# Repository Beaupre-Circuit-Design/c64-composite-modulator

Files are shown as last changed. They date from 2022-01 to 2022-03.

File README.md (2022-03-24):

# c64-rf-modulator-replacement
C64 Composite/S-Video RF Modulator Replacement

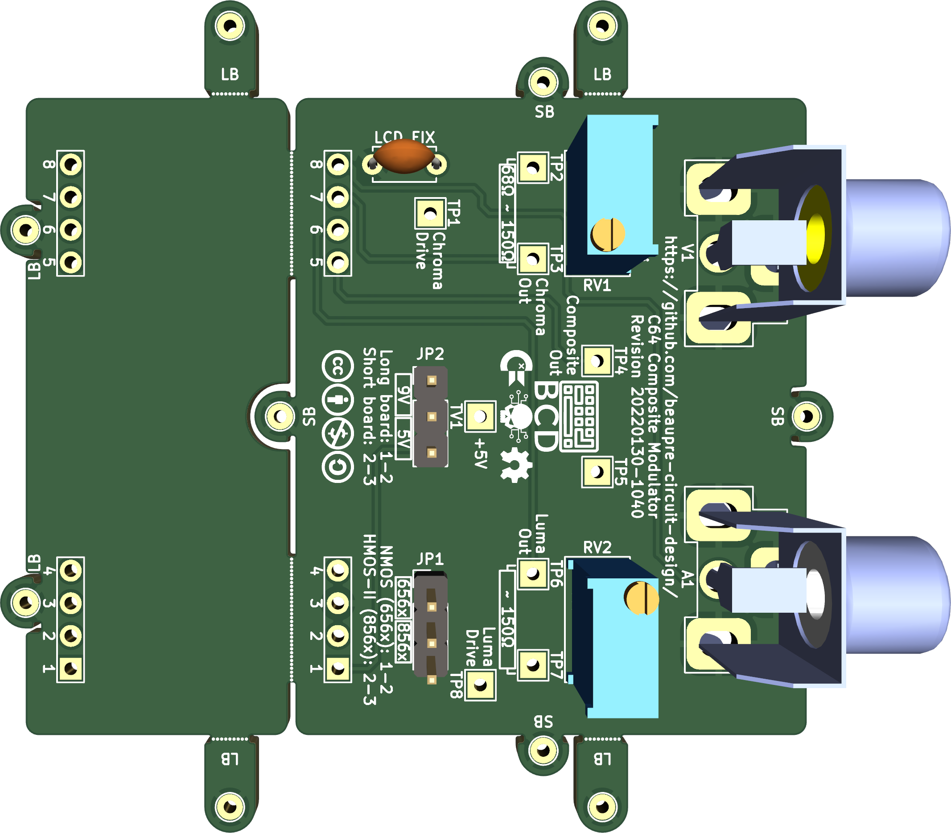
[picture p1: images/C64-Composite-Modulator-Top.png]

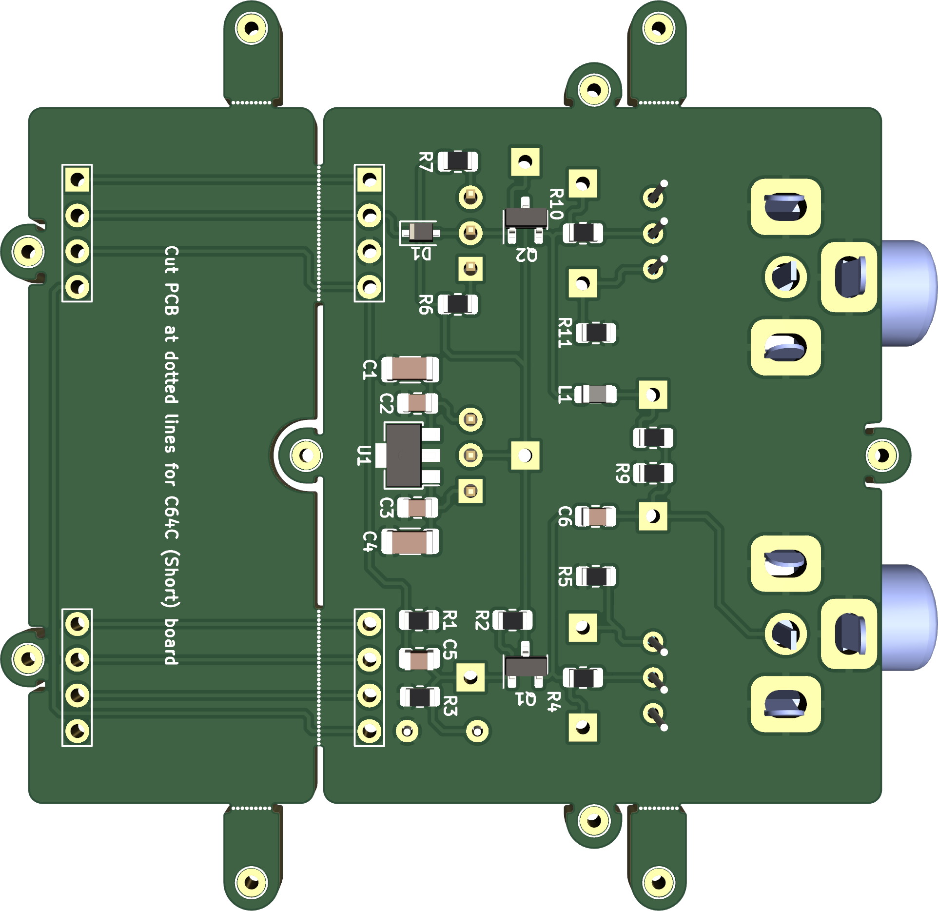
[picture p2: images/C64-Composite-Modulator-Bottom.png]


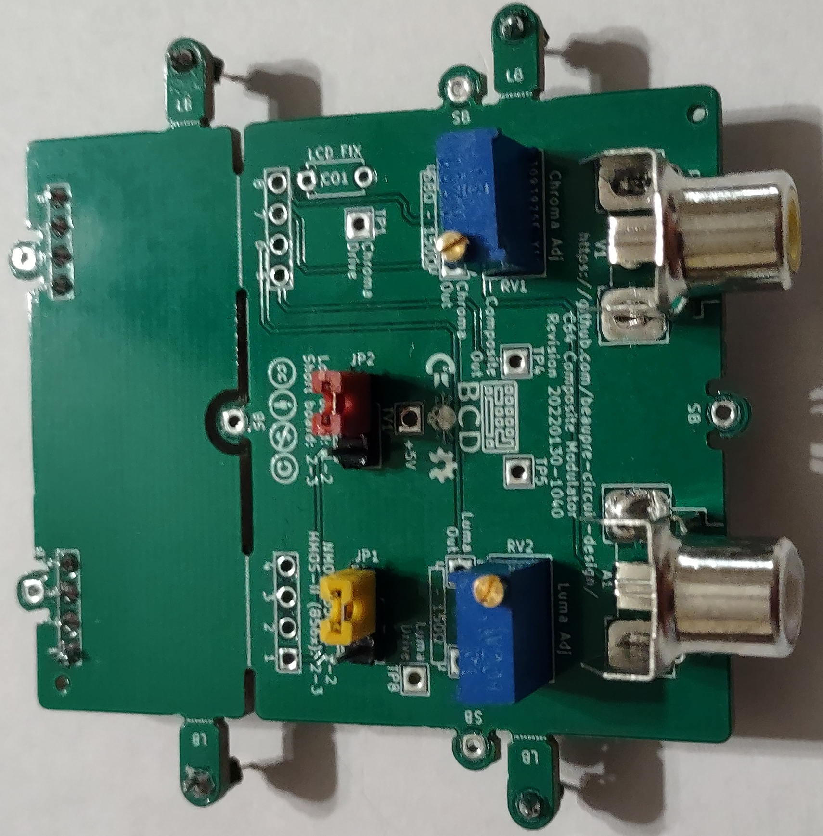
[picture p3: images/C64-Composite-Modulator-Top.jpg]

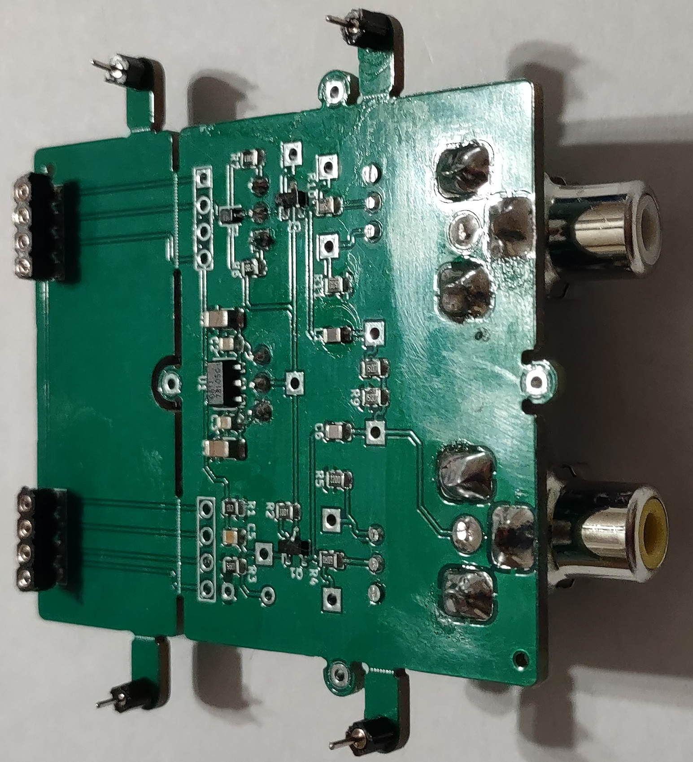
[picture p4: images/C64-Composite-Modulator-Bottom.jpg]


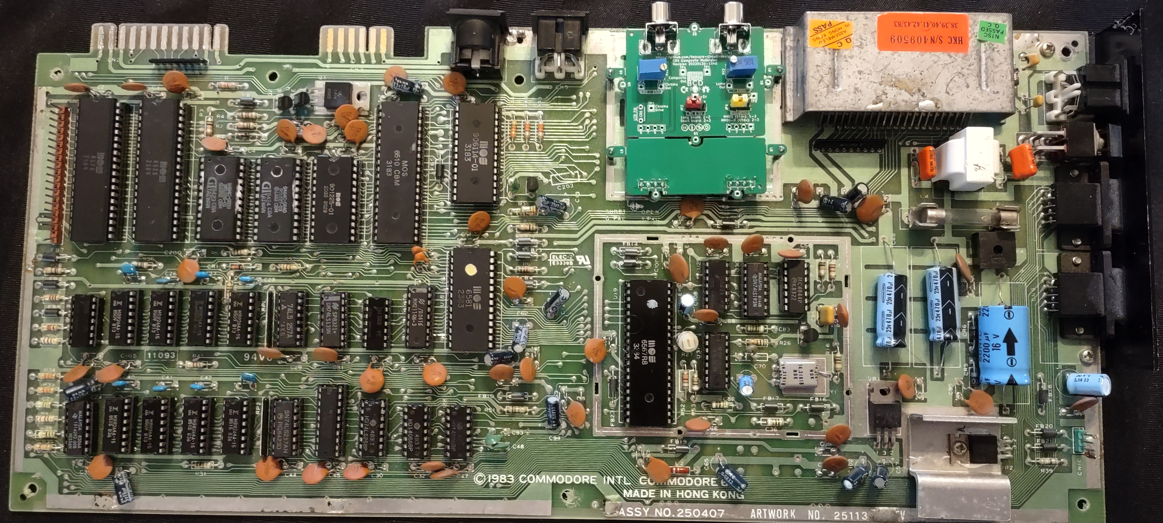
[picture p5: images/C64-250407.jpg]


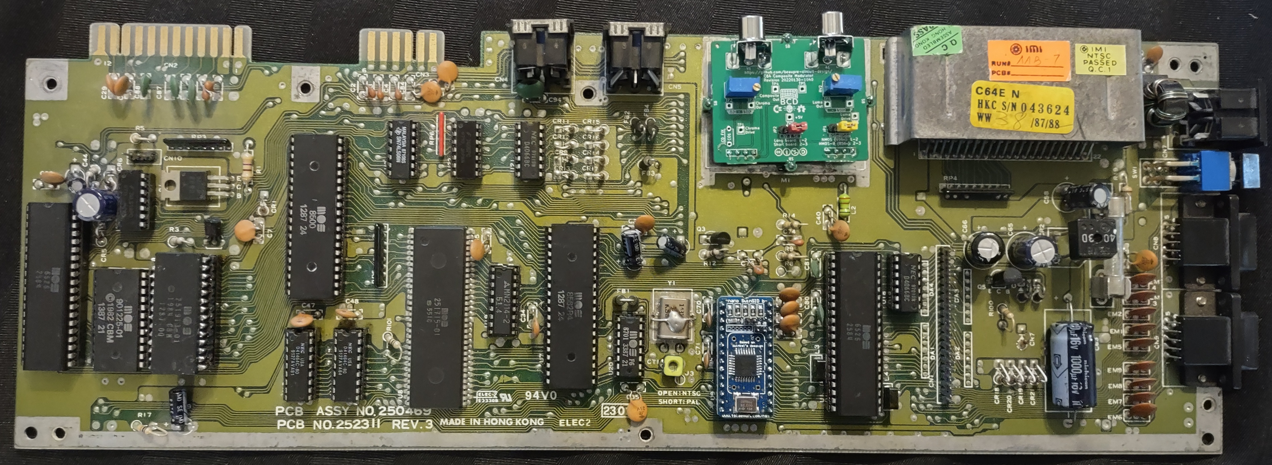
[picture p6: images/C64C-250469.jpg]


## Quick Links
* [Schematic](pdf/C64-Composite-Modulator.pdf)

* [Gerber Files](./gerbers)

* [PCB Renderings](./images)

* [Photos](./images)

# Introduction 
This is a remix of mbarszcz-pcb's version of a C64 RF Modulator replacement based on the schematics of similar designs like [Zero-X/OMS's Modified Commodore RF Modulator Design](images/zerox-oms-modulator_simple-schematic.png) and [JMP$FCE2's S-Video only design](images/jmp$fce2-schematic.png). This board can be used to replace a damaged or defective RF modulator in your C64, to improve the sharpness of your video output, or as a modern solution to replace the composite/luma/chroma output functionality of the original modulator on new motherboards such as the SixtyClone or Bwack’s KU-14194.

This design has a few goals that set it apart from the others:

1. It is a universal solution that fits and is electrically compatible with both the C64 and C64C without having to change components on the board or run jumper wires for power.

2. It is inexpensive to build with only a single, small PCB and SMD components that can be assemble by most rapid prototyping compagnies (everything included for JLCPCB but can be easilly adapted for any other service.)

3. It provides high quality S-Video (Y/C) output on the standard A/V output of the C64 while maintaining composite video output for compatibility.

4. It provides adjustable luma/chroma output levels to fine-tune the S-video signal. This allows for the best possible compatibility with a wide variety of different board revisions, VIC chips, aging components and monitors. Adjustable levels mean this board can also be used with s-video cables with or without an inline resistor to eliminate “checkerboarding” caused by too high of a chroma level.

# Compatibility
This RF modulator replacement is compatible with motherboard revisions 250407, 250425, 250466, and 250469, and both NTSC and PAL VIC-II chips. I have not tested it, but I believe it should also be compatible with Bwack's KU-14194 board as well since it uses the standard longboard RF modulator. It is not compatible, however, with the early revision 326298-01 boards with the 5 Pin AV Output. This revision uses a different modulator pin layout, and the video signals are not combined in the modulator. They are instead processed with discrete components inside the VIC-II can.

# Gathering the components
Kicad files are available for you to view or modify as you see fit. Gerber and SMT positioning files are available that can be uploaded directly to JLCPCB to make and assemble your own boards. The Bill of Materials (BOM) can be found [here](C64-Composite-Modulator-Bom.xlsx) with example parts from LCSC and Digikey.

I strongly recommend building the entire board, if you choose to do so, there are a few components that can be omitted in different situations to decrease the cost at the expense of features and flexibility.

## Trimmers
The trim pots used to adjust the luma and chroma are the most expensive components in this project. I highly recommend using them, but if you choose, you may ommit the trimmer pots and install 150Ω resistors instead. This won't give you the precision adjustment of the trimmers, but it will be close enough for most configurations. You can experiment with different fixed value resistors between 100-1KΩ if you want to change fixed output levels.

## No Composite Video
I have not seen any improvement in S-video quality by omitting the composite video components, but if you really don’t want composite output, L1, R8, R9, C6 and V1 can be omitted from the build.

## No Audio Output
A1 can be omitted from the build if you do not want an audio output. Audio will still be available thru the standard A/V output of the C64.

## No Voltage Regulator
If you are only ever going to use the RF modulator replacement on a C64C 250469 short board, you don’t need the voltage regulator or the input/output capacitors since 5V is provided directly to the modulator on pin 1. This means you can omit C1, C2, C3, C4, U1 from the build and permanently jump JP3 pin 2 and 3.

# Building the board
If you wish to assemble the board yourself, i greatly recommend having a SMD Stainless Steel stencil made with your PCB order if you're going with hot air or oven reflow. First step is to start with soldering all the SMD components then the throught holes ones. Finish off by removing the flux residue with some cotton swabs or a brush and isopropyl alcohol.

# Installing the board
First, you need to remove the old RF modulator. This can be a bit tricky as the large metal can will suck the heat right out of the iron. I can’t help you much here, but I can only suggest you use a soldering iron with plenty of heat, use a wide tip, to take your time, and don't rip off any traces. The new board can then be installed one of two ways.

I do not recommend soldering it directly to the motherboard, it will make things much more difficult to remove if you want to upgrade to something else in the futur or come back to the stock modulator.

The PCB can be cut at the dotted lines if you plan to install it on a C64C 250469 short board to reduce footprint.

First solder all the pin headers on the underside, use the LB positions for the large boards and SB for the short boards. Then install the females headers on the motherboards. I personally prefer the rounded pins/receptacles headers but square work just fine too. Solder the female signal headers before the support (LB/SB) headers.

# Adjustments

## Configuring the mainboard
If you are using the longboard (Rev 250407, 250425, 240441, 250466), ground is provided by the support headers, so there is no need to change the G.PAL/I.PAL jumper on the motherboard.

## Jumper Settings
JP1 need to be set accordingly to your VIC-II version, use position 1-2 for NMOS (656x) and 2-3 for HMOS-II (856x).

JP2 control the use of the on-board voltage regulator. For long boards (250407, 250425, and 250466), use position 1-2 to enable the on-board regulator and for C64C short boards (250469) use position 2-3 to bypass it since the board already provide 5v. If you're not sure, check the voltage at pin 2 of JP2. If you get 5v, use position 2-3, else 1-2.

## Adjusting the Output Level
If you choose to include adjustable potentiometers in your build, a counter-clockwise adjustment on the luma (Y) and chroma (C) potentiometers will reduce the output level. A clockwise adjustment will increase the output level. My recommendation is to start with both adjustments fully counter-clockwise and increase as necessary. The levels can be set with a scope or simply “by eye” depending on the tools you have available.

An ideal chroma signal should be ~300mV peak-to-peak (mesured at TP3). The adjustment on the board should allow you to adjust it from approximately ~250mV - 1.7V. This range allows you to dial back the output for use with a standard S-video cable or to turn it up to compensate for the cables with the inline 330-1K resistor. Some monitors don't care if the signal is too hot, others will give you an ugly checkered pattern (especially LCDs). If you don't have an oscilloscope to measure the peak-to-peak voltage, start with the chroma pot fully counter-clockwise and increase it until the colors are sufficiently saturated. If you go too far, the image will begin to look “grainy” or have a checkerboard pattern.

Officially, an ideal luma signal should be 1V PP (including the sync pulse, mesured at TP6). Depending on the output of the VIC-II chip you are using, the adjustment on the board should allow you to adjust it from approximately ~575mV-1.5V PP. The original breadbins output a signal around 1.2V PP, while the later C64Cs were closer to an “in-spec” 1V PP. On some monitors though 1V PP can look too look dark (requiring you to turn up the contrast on your monitor). If using a scope, I would adjust it to approximately 1.1V PP. If adjusting by eye, start low and increase the level until the light blue text is reasonably legible against the dark blue background. If the border and text start to look “white” you have gone too far. Another good test on a CRT is white text on a black background. If the white text is blooming, you should back the signal off. The effect will be very similar to having the contrast set too high.

Composite video output remains at a fixed output level regardless of the Y and C adjustment pots.

# A note on use with LCD Monitors and Checkerboarding
If you are still getting checkerboarding even after adjusting the potentiometers, try populating CO1 with a 330pF Resistor (you can experiement with different values to see what works best with your setup). This combines with R3 to create an RC filter that seems to help eliminate this. There seems to be a degree of variablility regarding different A->D conversion cirtuitry used in different brands of LCD monitors and in devices like the RetroTink2X or OSSC that makes some displays more susceptable to checkerboarding. CRT monitors are not as susceptable to this behavior.

# Changelog
* Rev 20210528-2008
  * Prototype
* Rev 20210531-2143 (Not working)
  * Move B1/B2 silkscreen reference to the right location.
  * Rotate JP1/JP2 so all the headers are aligned to the same side (Forgot to update the silkscreen)
  * Switch to a BC847 transistor but forgot to update the footprint.
* Rev 20220130-1040
  * Corrected aligment of the support headers.
  * Corrected wrong pinout on Q1/Q2.
  * Remove the dual-sid option, not really useful.
  * Change A1 to a RCA Phono jack.
  * Remove B1/B2, use the trimmer pot pads instead if replacing them with a fixed resistor value.
  * Change the footprint of the LCD FIX capacitor for a throught-hole.
  * PCB Layout rework.
  * Fully assembled and tested on both C64 and C64C motherboards.

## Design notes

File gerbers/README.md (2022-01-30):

**Always use the latest revision PCB.**

Recommended board values:
* PCB Thickness: 1.6mm
* Copper Weight 1oz
* Surface Finish - Personal preference

Theses files should be zipped together and uploaded for PCB fabrication:
* C64-Composite-Modulator-B_Cu.gbl
* C64-Composite-Modulator-B_Mask.gbs
* C64-Composite-Modulator-B_Paste.gbp
* C64-Composite-Modulator-B_SilkS.gbo
* C64-Composite-Modulator-Edge_Cuts.gm1
* C64-Composite-Modulator-F_Cu.gtl
* C64-Composite-Modulator-F_Mask.gts
* C64-Composite-Modulator-F_Paste.gtp
* C64-Composite-Modulator-F_SilkS.gto
* C64-Composite-Modulator-NPTH-drl_map.gbr
* C64-Composite-Modulator-NPTH.drl
* C64-Composite-Modulator-PTH-drl_map.gbr
* C64-Composite-Modulator-PTH.drl 

Theses files are for the SMT assembly services, when ordering, request for bottom side assembly:
* BOM and footprint:
  * JLCPCB-SMT-C64-Composite-Modulator-bom.xlsx
* SMT positions:
  * JLCPCB-SMT-C64-Composite-Modulator-bottom-pos.xlsx

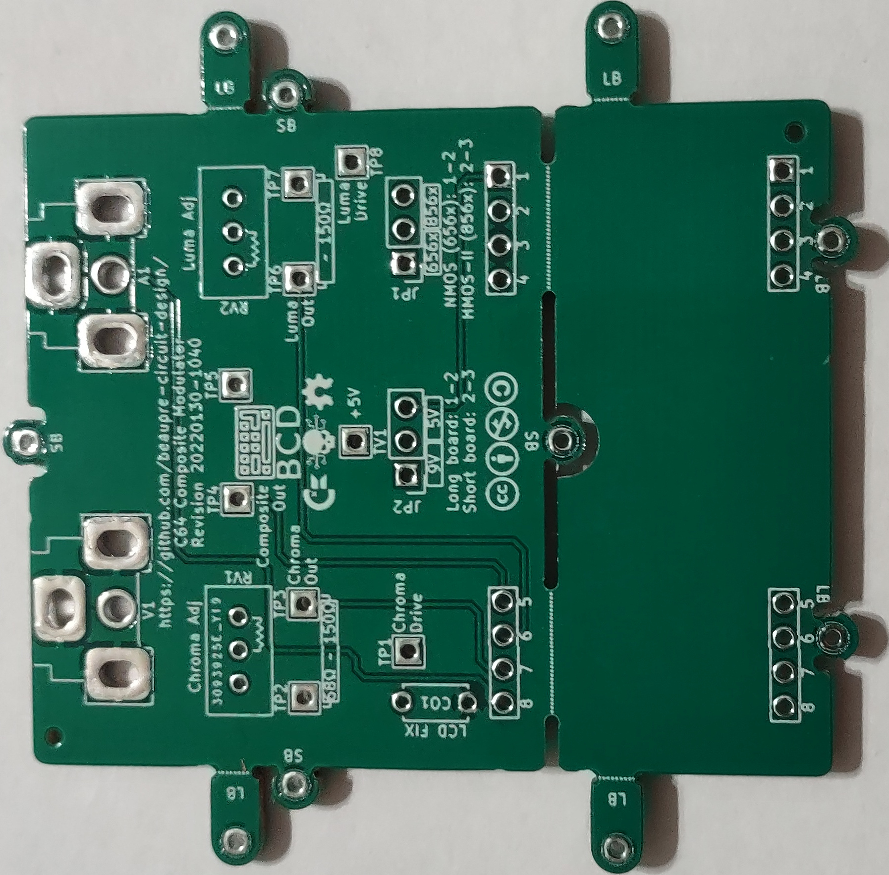
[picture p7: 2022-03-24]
images/C64-Composite-Modulator-Top-Unpopulated.jpg

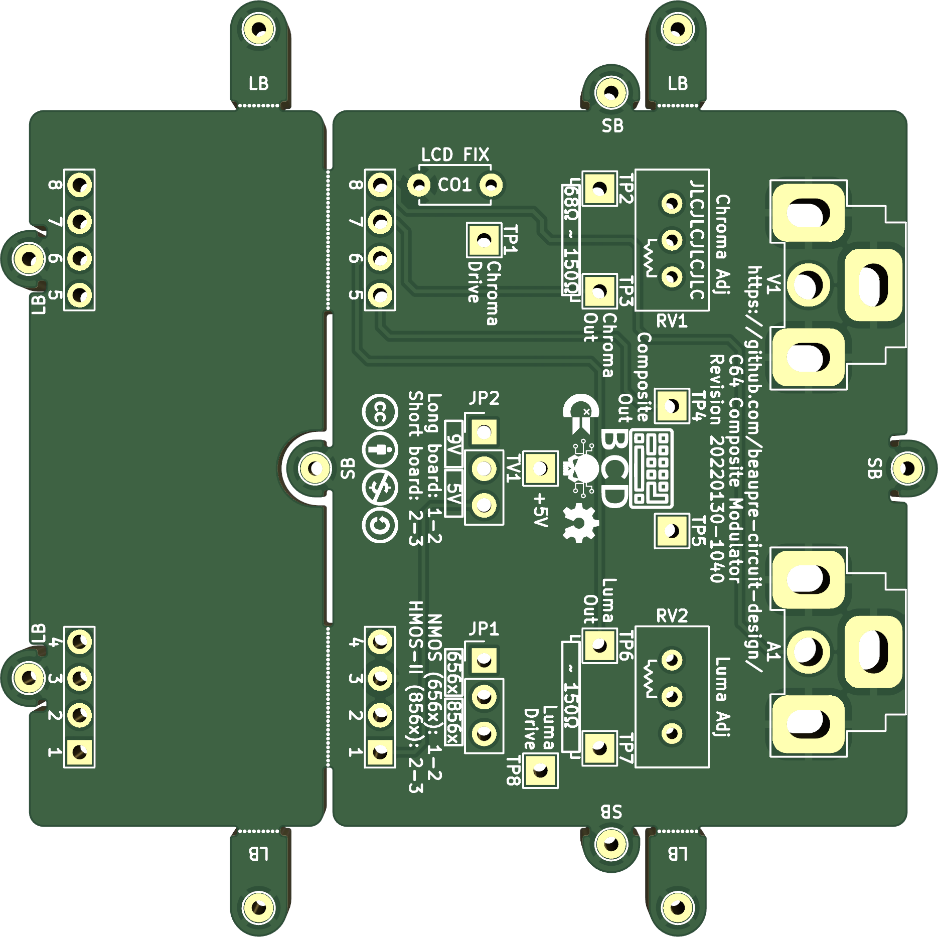
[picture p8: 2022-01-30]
images/C64-Composite-Modulator-Top-Unpopulated.png

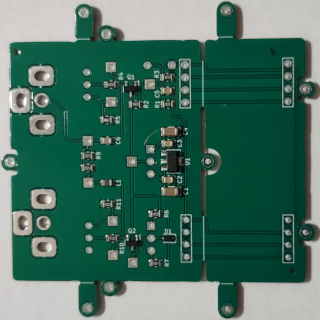
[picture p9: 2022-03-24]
images/C64-Composite-Modulator-Bottom-Unpopulated_Small.jpg

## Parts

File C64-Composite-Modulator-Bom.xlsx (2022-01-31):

Ref | Value | Footprint | Datasheet | Manufacturer | Mfr.Part | LCSC | Digikey | Notes
A1 | Conn_Coaxial | CUI_Devices:RCJ-013 | https://www.cuidevices.com/product/resource/digikeypdf/rcj-01x.pdf | CUI Devices | RCJ-014 |  | CP-1403-ND
C1 | 10uF | Capacitor_SMD:C_1206_3216Metric | https://datasheet.lcsc.com/lcsc/1810221112_Samsung-Electro-Mechanics-CL31A106KBHNNNE_C13585.pdf | Samsung Electro-Mechanics | CL31A106KBHNNNE | C13585 | 1276-2876-1-ND
C2 | 33nF | Capacitor_SMD:C_0805_2012Metric | https://datasheet.lcsc.com/lcsc/1811061723_FH-Guangdong-Fenghua-Advanced-Tech-0805B333K500NT_C1739.pdf | FH(Guangdong Fenghua Advanced Tech) | 0805B333K500NT | C1739 | 1276-1796-1-ND
C3 | 100nF | Capacitor_SMD:C_0805_2012Metric | https://datasheet.lcsc.com/lcsc/1810191216_Samsung-Electro-Mechanics-CL21B104KCFNNNE_C28233.pdf | Samsung Electro-Mechanics | CL21B104KCFNNNE | C28233 | 1276-6840-1-ND
C4 | 10uF | Capacitor_SMD:C_1206_3216Metric | https://datasheet.lcsc.com/lcsc/1810221112_Samsung-Electro-Mechanics-CL31A106KBHNNNE_C13585.pdf | Samsung Electro-Mechanics | CL31A106KBHNNNE | C13585 | 1276-2876-1-ND
C5 | 330pF | Capacitor_SMD:C_0805_2012Metric | https://datasheet.lcsc.com/lcsc/1810191220_Samsung-Electro-Mechanics-CL21B331KBANNNC_C51207.pdf | Samsung Electro-Mechanics | CL21B331KBANNNC | C51207 | 1276-1765-1-ND
C6 | 68pF | Capacitor_SMD:C_0805_2012Metric | https://datasheet.lcsc.com/lcsc/1912112237_Samsung-Electro-Mechanics-CL21C680JBANNNC_C193697.pdf | Samsung Electro-Mechanics | CL21C680JBANNNC | C193697 | 1276-1136-1-ND
CO1 | 330pF | Capacitor_THT:C_Disc_D4.7mm_W2.5mm_P5.00mm | https://datasheet.lcsc.com/lcsc/1912111437_TDK-CK45-B3AD331KYVNA_C342340.pdf | TDK | CK45-B3AD331KYVNA | C342340 | 445-CK45-B3AD331KYVNA-ND | Optionnal, install for LCD fix if needed
D1 | 1N4148WS | Diode_SMD:D_SOD-323F | https://datasheet.lcsc.com/lcsc/1810101110_Changjiang-Electronics-Tech-CJ-1N4148WS_C2128.pdf | Changjiang Electronics Tech | 1N4148WS | C2128 | 1N4148WSFSCT-ND
JP1 | Jumper_3_Open | Connector_PinHeader_2.54mm:PinHeader_1x03_P2.54mm_Vertical | https://datasheet.lcsc.com/lcsc/1811132313_BOOMELE-Boom-Precision-Elec-C49257_C49257.pdf | BOOMELE(Boom Precision Elec) | C49257 | C49257 | 609-3461-ND
JP2 | Jumper_3_Open | Connector_PinHeader_2.54mm:PinHeader_1x03_P2.54mm_Vertical | https://datasheet.lcsc.com/lcsc/1811132313_BOOMELE-Boom-Precision-Elec-C49257_C49257.pdf | BOOMELE(Boom Precision Elec) | C49257 | C49257 | 609-3461-ND
L1 | 10uH | Inductor_SMD:L_0805_2012Metric | https://datasheet.lcsc.com/lcsc/2110081230_Sunlord-SDFL2012S100KTF_C1046.pdf | Sunlord | SDFL2012S100KTF | C1046 | 587-2452-1-ND
Q1 | BC847C | Package_TO_SOT_SMD:SOT-23 | https://datasheet.lcsc.com/lcsc/1811141238_Nexperia-BC847C-215_C8664.pdf | Nexperia | BC847C,215 | C8664 | 1727-2924-1-ND
Q2 | BC847C | Package_TO_SOT_SMD:SOT-23 | https://datasheet.lcsc.com/lcsc/1811141238_Nexperia-BC847C-215_C8664.pdf | Nexperia | BC847C,215 | C8664 | 1727-2924-1-ND
R1 | 1KΩ | Resistor_SMD:R_0805_2012Metric | https://datasheet.lcsc.com/lcsc/1811022111_UNI-ROYAL-Uniroyal-Elec-0805W8F1001T5E_C17513.pdf | UNI-ROYAL(Uniroyal Elec) | 0805W8F1001T5E | C17513 | 13-RC0805JR-131KLCT-ND
R2 | 3K3Ω | Resistor_SMD:R_0805_2012Metric | https://datasheet.lcsc.com/lcsc/1809140022_UNI-ROYAL-Uniroyal-Elec-0805W8F3301T5E_C26010.pdf | UNI-ROYAL(Uniroyal Elec) | 0805W8F3301T5E | C26010 | 13-RC0805JR-133K3LCT-ND
R3 | 5K6Ω | Resistor_SMD:R_0805_2012Metric | https://datasheet.lcsc.com/lcsc/1810301830_UNI-ROYAL-Uniroyal-Elec-0805W8F5601T5E_C4382.pdf | UNI-ROYAL(Uniroyal Elec) | 0805W8F5601T5E | C4382 | 13-RC0805JR-105K6LCT-ND
R4 | 68Ω | Resistor_SMD:R_0805_2012Metric | https://datasheet.lcsc.com/lcsc/1810301620_UNI-ROYAL-Uniroyal-Elec-0805W8F680JT5E_C17802.pdf | UNI-ROYAL(Uniroyal Elec) | 0805W8F680JT5E | C17802 | 804-1106-1-ND
R5 | 220Ω | Resistor_SMD:R_0805_2012Metric | https://datasheet.lcsc.com/lcsc/1810241809_UNI-ROYAL-Uniroyal-Elec-0805W8F2200T5E_C17557.pdf | UNI-ROYAL(Uniroyal Elec) | 0805W8F2200T5E | C17557 | 13-RC0805JR-13220RLCT-ND
R6 | 470Ω | Resistor_SMD:R_0805_2012Metric | https://datasheet.lcsc.com/lcsc/1811050105_UNI-ROYAL-Uniroyal-Elec-0805W8F4700T5E_C17710.pdf | UNI-ROYAL(Uniroyal Elec) | 0805W8F4700T5E | C17710 | 13-RC0805JR-13470RLCT-ND
R7 | 1KΩ | Resistor_SMD:R_0805_2012Metric | https://datasheet.lcsc.com/lcsc/1811022111_UNI-ROYAL-Uniroyal-Elec-0805W8F1001T5E_C17513.pdf | UNI-ROYAL(Uniroyal Elec) | 0805W8F1001T5E | C17513 | 13-RC0805JR-131KLCT-ND
R8 | 150Ω | Resistor_SMD:R_0805_2012Metric | https://datasheet.lcsc.com/lcsc/1810301815_UNI-ROYAL-Uniroyal-Elec-0805W8F1500T5E_C17471.pdf | UNI-ROYAL(Uniroyal Elec) | 0805W8F1500T5E | C17471 | 13-RC0805JR-13150RLCT-ND
R9 | 150Ω | Resistor_SMD:R_0805_2012Metric | https://datasheet.lcsc.com/lcsc/1810301815_UNI-ROYAL-Uniroyal-Elec-0805W8F1500T5E_C17471.pdf | UNI-ROYAL(Uniroyal Elec) | 0805W8F1500T5E | C17471 | 13-RC0805JR-13150RLCT-ND
R10 | 75Ω | Resistor_SMD:R_0805_2012Metric | https://datasheet.lcsc.com/lcsc/1810301620_UNI-ROYAL-Uniroyal-Elec-0805W8F750JT5E_C17820.pdf | UNI-ROYAL(Uniroyal Elec) | 0805W8F750JT5E | C17820 | 13-RC0805FR-1375RLCT-ND
R11 | 150Ω | Resistor_SMD:R_0805_2012Metric | https://datasheet.lcsc.com/lcsc/1810301815_UNI-ROYAL-Uniroyal-Elec-0805W8F1500T5E_C17471.pdf | UNI-ROYAL(Uniroyal Elec) | 0805W8F1500T5E | C17471 | 13-RC0805JR-13150RLCT-ND
RV1 | 1KΩ | Potentiometer_THT:Potentiometer_Bourns_3296W_Vertical | https://datasheet.lcsc.com/lcsc/1811011713_BOCHEN-Chengdu-Guosheng-Tech-3296W-1-102_C118949.pdf | BOCHEN(Chengdu Guosheng Tech) | 3296W-1-102 | C118949 | 3296W-102-ND
RV2 | 500Ω | Potentiometer_THT:Potentiometer_Bourns_3296W_Vertical | https://datasheet.lcsc.com/lcsc/1811101609_BOCHEN-Chengdu-Guosheng-Tech-3296W-1-500_C118908.pdf | BOCHEN(Chengdu Guosheng Tech) | 3296W-1-500 | C118908 | 3296W-500-ND
U1 | 78L05G-AB3-R | Package_TO_SOT_SMD:SOT-89-3 | https://datasheet.lcsc.com/lcsc/1809200029_UTC-Unisonic-Tech-78L05G-AB3-R_C71136.pdf | UTC(Unisonic Tech) | 78L05G-AB3-R | C71136 | ZSR500GCT-ND
V1 | Conn_Coaxial | CUI_Devices:RCJ-014 | https://www.cuidevices.com/product/resource/digikeypdf/rcj-01x.pdf | CUI Devices | RCJ-014 |  | CP-1403-ND

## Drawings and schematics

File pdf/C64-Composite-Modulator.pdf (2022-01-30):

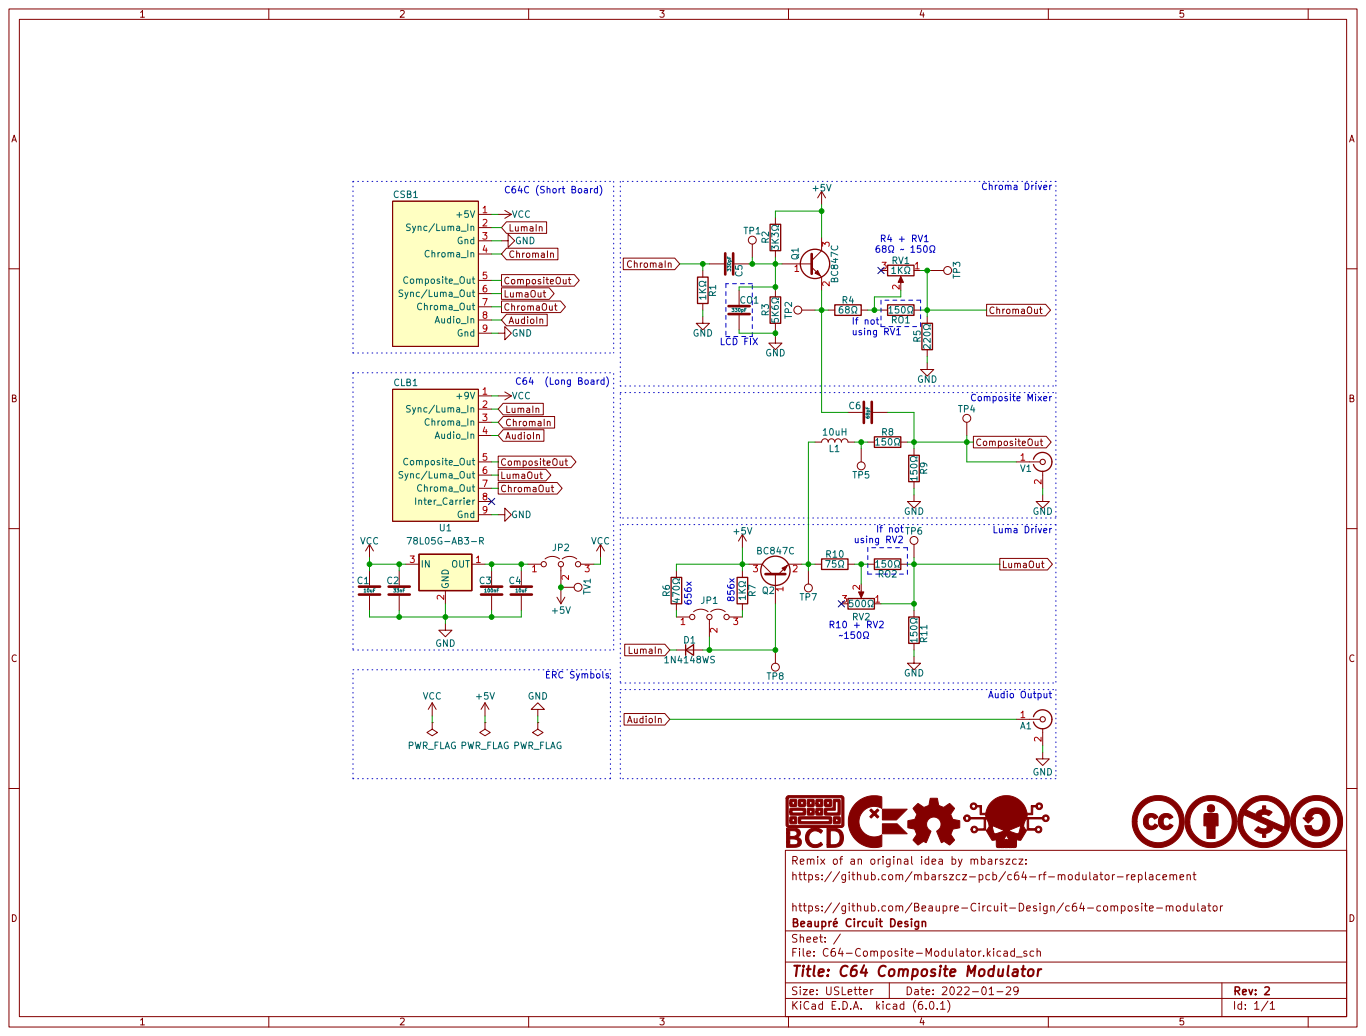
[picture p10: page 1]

1N4148WS GND
LumaOut CompositeOut AudioIn ChromaOut ChromaIn ChromaIn

Remix of an original idea by mbarszcz: +5V

https://github.com/mbarszcz-pcb/c64-rf-modulator-replacement

https://github.com/Beaupre-Circuit-Design/c64-composite-modulator
File: C64-Composite-Modulator.kicad_sch Sheet: / þÿBeaupré Circuit Design

Id: 1/1 Title: C64 Composite Modulator

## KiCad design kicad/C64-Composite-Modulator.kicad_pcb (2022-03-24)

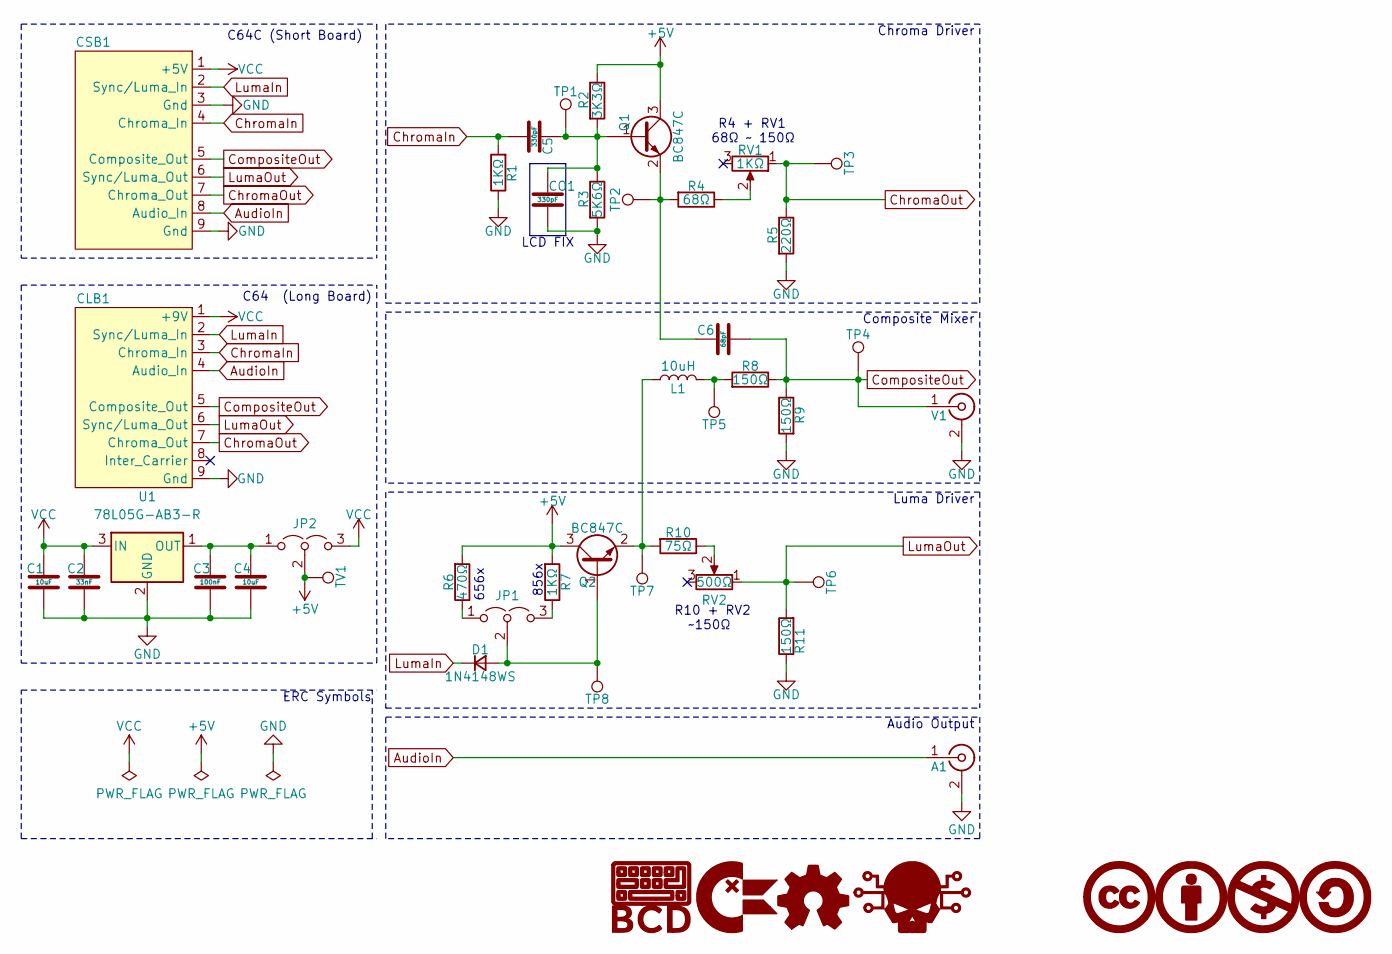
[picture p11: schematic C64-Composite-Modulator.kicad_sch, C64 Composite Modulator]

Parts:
A1: Conn_Coaxial; RCJ-013; Mfr.Part RCJ-014; Digikey CP-1403-ND
C1, C4: 10uF; C_1206_3216Metric; Mfr.Part CL31A106KBHNNNE; LCSC C13585
C2: 33nF; C_0805_2012Metric; Mfr.Part 0805B333K500NT; LCSC C1739
C3: 100nF; C_0805_2012Metric; Mfr.Part CL21B104KCFNNNE; LCSC C28233
C5: 330pF; C_0805_2012Metric; Mfr.Part CL21B331KBANNNC; LCSC C51207
C6: 68pF; C_0805_2012Metric; Mfr.Part CL21C680JBANNNC; LCSC C193697
CLB1: Modulator_Board_To_Long_Board; Modulator to Long-Board support; Mfr.Part C49257; Digikey 1212-1172-ND
CO1: 330pF; C_Disc_D4.7mm_W2.5mm_P5.00mm; Mfr.Part CK45-B3AD331KYVNA; LCSC C342340
CSB1: Modulator_Board_To_Short_Board; Modulator to Short-Board support; Mfr.Part C49257; Digikey 1212-1172-ND
D1: 1N4148WS; D_SOD-323F; Mfr.Part 1N4148WS; LCSC C2128
G1: BCD_Logo; BCD_Logo_5mm
G2: ChickenLips; ChickenLips_2.5mm
G3: OpenSource_Hardware; Open_Source_Hardware_2.5mm
G4: Skull; Skull_2.5mm
G5: CreativeCommons; CreativeCommons_2.5mm
G6: CreativeCommons_Attribution; CreativeCommons_Attribution_2.5mm
G7: CreativeCommons_NonCommercial; CreativeCommons_NonCommercial_2.5mm
G8: CreativeCommons_ShareAlike; CreativeCommons_ShareAlike_2.5mm
JP1, JP2: Jumper_3_Open; PinHeader_1x03_P2.54mm_Vertical; Mfr.Part C49257; LCSC C49257
L1: 10uH; L_0805_2012Metric; Mfr.Part SDFL2012S100KTF; LCSC C1046
Q1, Q2: BC847C; SOT-23; Mfr.Part BC847C,215; LCSC C8664
R1, R7: 1KΩ; R_0805_2012Metric; Mfr.Part 0805W8F1001T5E; LCSC C17513
R2: 3K3Ω; R_0805_2012Metric; Mfr.Part 0805W8F3301T5E; LCSC C26010
R3: 5K6Ω; R_0805_2012Metric; Mfr.Part 0805W8F5601T5E; LCSC C4382
R4: 68Ω; R_0805_2012Metric; Mfr.Part 0805W8F680JT5E; LCSC C17802
R5: 220Ω; R_0805_2012Metric; Mfr.Part 0805W8F2200T5E; LCSC C17557
R6: 470Ω; R_0805_2012Metric; Mfr.Part 0805W8F4700T5E; LCSC C17710
R8, R9, R11: 150Ω; R_0805_2012Metric; Mfr.Part 0805W8F1500T5E; LCSC C17471
R10: 75Ω; R_0805_2012Metric; Mfr.Part 0805W8F750JT5E; LCSC C17820
RV1: 1KΩ; Potentiometer_Bourns_3296W_Vertical; Mfr.Part 3296W-1-102; LCSC C118949
RV2: 500Ω; Potentiometer_Bourns_3296W_Vertical; Mfr.Part 3296W-1-500; LCSC C118908
TP1, TP2, TP3, TP4, TP5, TP6, TP7, TP8: TestPoint; TestPoint_THTPad_2.0x2.0mm_Drill1.0mm
TV1: TestPoint; TestPoint_THTPad_2.0x2.0mm_Drill1.0mm
U1: 78L05G-AB3-R; SOT-89-3; Mfr.Part 78L05G-AB3-R; LCSC C71136
V1: Conn_Coaxial; RCJ-014; Mfr.Part RCJ-014; Digikey CP-1403-ND

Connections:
+5V: JP2.2 (C), Q1.3 (C), Q2.3 (C), R2.1, R6.2, R7.2, TV1.1
AudioIn: A1.1 (In), CLB1.4 (Audio_In), CSB1.8 (Audio_In)
ChromaIn: C5.2, CLB1.3 (Chroma_In), CSB1.4 (Chroma_In), R1.2
ChromaOut: CLB1.7 (Chroma_Out), CSB1.7 (Chroma_Out), R5.1, RV1.1, TP3.1
CompositeOut: C6.1, CLB1.5 (Composite_Out), CSB1.5 (Composite_Out), R8.1, R9.1, TP4.1, V1.1 (In)
GND: A1.2 (Ext), C1.2, C2.2, C3.2, C4.2, CLB1.9 (Gnd), CO1.2, CSB1.3 (Gnd), CSB1.9 (Gnd), R1.1, R3.2, R5.2, R9.2, R11.1, U1.2 (GND), V1.2 (Ext)
LumaIn: CLB1.2 (Sync/Luma_In), CSB1.2 (Sync/Luma_In), D1.1 (K)
LumaOut: CLB1.6 (Sync/Luma_Out), CSB1.6 (Sync/Luma_Out), R11.2, RV2.1, TP6.1
unnamed: C3.1, C4.1, JP2.1 (A), U1.1 (OUT)
unnamed: C5.1, CO1.1, Q1.1 (B), R2.2, R3.1, TP1.1
unnamed: C6.2, Q1.2 (E), R4.2, TP2.1
unnamed: D1.2 (A), JP1.2 (C), Q2.1 (B), TP8.1
unnamed: JP1.1 (A), R6.1
unnamed: JP1.3 (B), R7.1
unnamed: L1.1, R8.2, TP5.1
unnamed: L1.2, Q2.2 (E), R10.2, TP7.1
unnamed: R4.1, RV1.2
unnamed: R10.1, RV2.2
VCC: C1.1, C2.1, CLB1.1 (+9V), CSB1.1 (+5V), JP2.3 (B), U1.3 (IN)

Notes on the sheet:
856x
R10 + RV2 ~150Ω
C64C (Short Board)
Luma Driver
Composite Mixer
C64 (Long Board)
ERC Symbols
Audio Output
R4 + RV1 68Ω ~ 150Ω
Chroma Driver
656x
LCD FIX

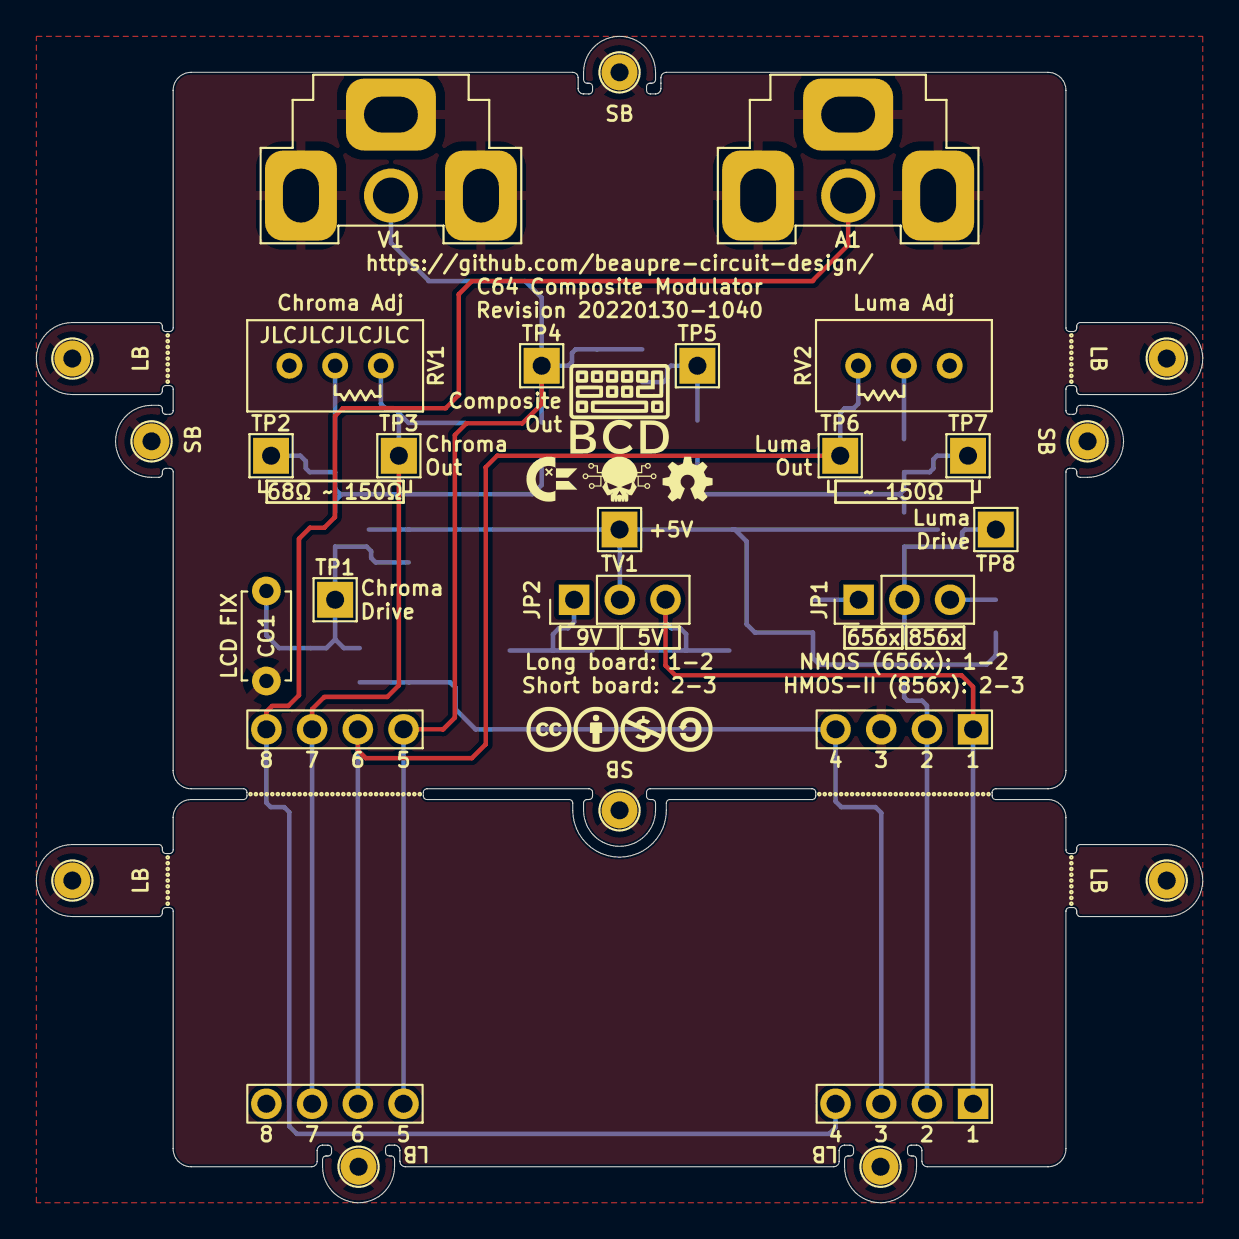
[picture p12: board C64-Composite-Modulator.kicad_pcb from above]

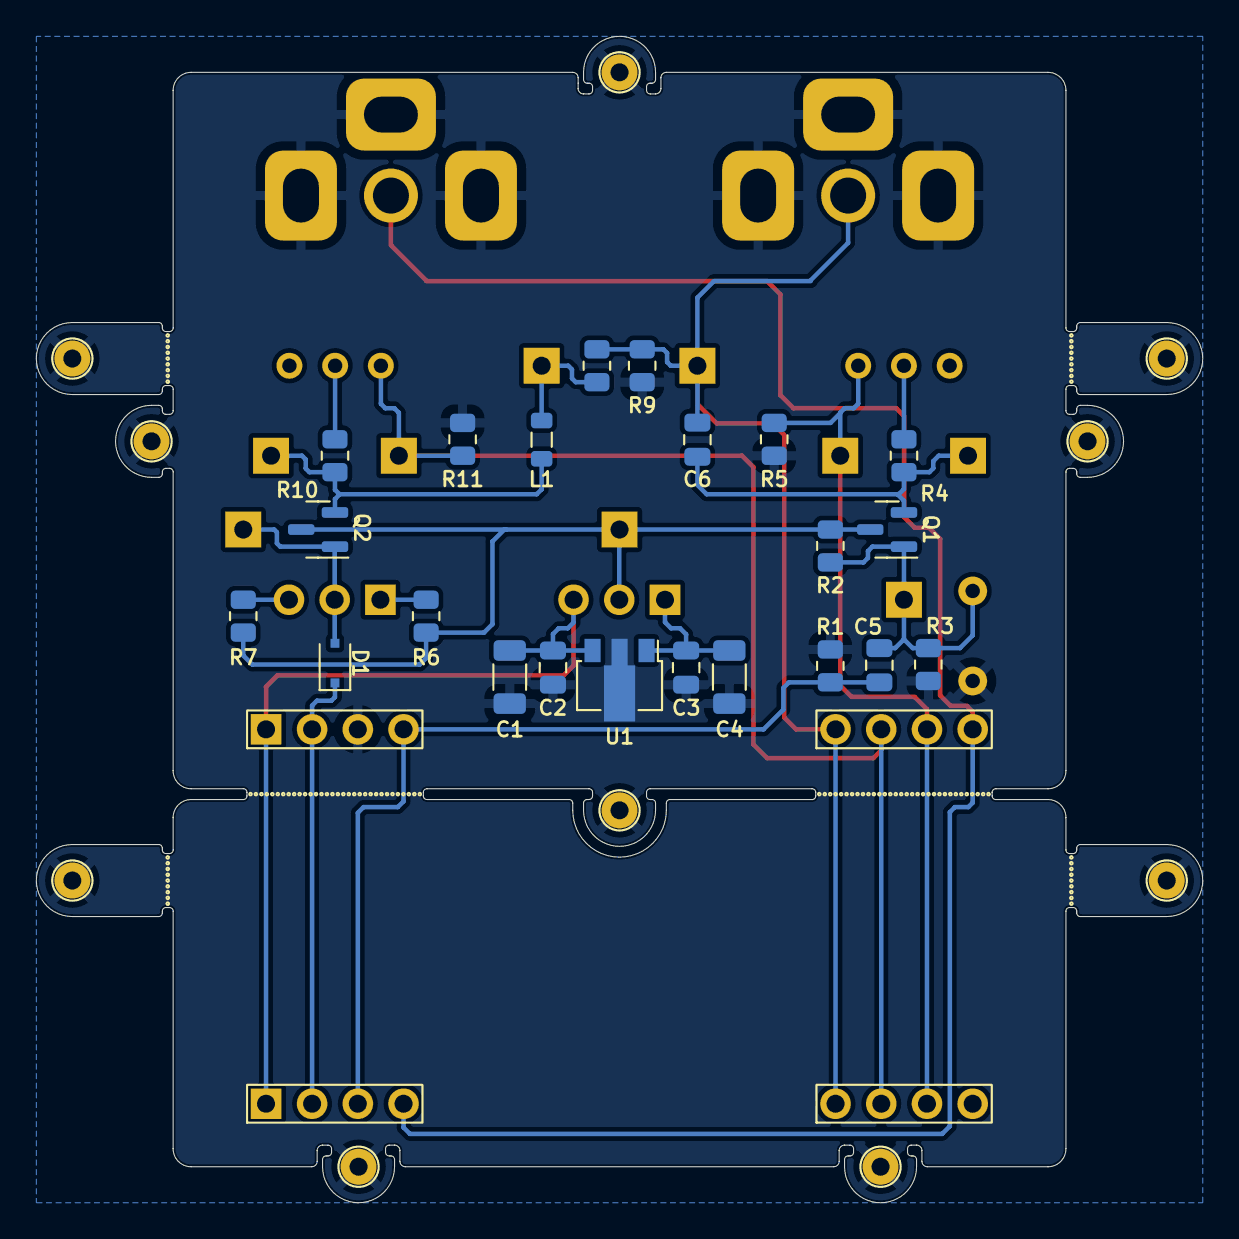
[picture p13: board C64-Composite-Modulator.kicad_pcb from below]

Board: 2 copper layers, 64.8 x 64.8 mm, 48 parts (22 on the bottom side), 19 nets.

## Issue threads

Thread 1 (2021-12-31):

Question about jumpers

jsanpe, 2021-12-31:
Hi,

I just finished assembling this board and I am facing some difficulties figuring out the right locations for the jumpers. Let me explain.

For JP1 (power regulator jumper) the schematic is this:
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

which seems to imply that shorting 1-2 would make it work for the 656x version of the VIC-II. However, the PCB silkscreen seems to contradict this:
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

with pins 1-2 being labeled as 856x.

The same situation seems to be happening with JP3 (power regulator).

I may be misinterpreting the silkscreen or schematic, in any case just wanted to double check with you.

Happy new year, and thanks for sharing this RF mod replacement implementation!

EddyBeaupre, 2022-01-30:
Hi,

Yes there are issues with the silkscreen on revision 20210531-2143 (it's reversed), and Q1/Q2 have the wrong pinout (BC847 is BEC, not CBE). It's been corrected in revision 20220130-1040. I am really sorry for this. I've just ordered a new batch to test, if you still want to make this modulator you may wish to wait until i've received the new prototypes and confirm that everything work.

Revision 20210531-2143 can be fix if you cut the traces for Q1/Q2 and rework them with the correct pinout with mod-wires. That's what i did to confirm that i had no other errors....

EddyBeaupre, 2022-03-23:
Got the new PCB and finally had time to assemble everything. I can confirm that the latest revision fix all the issues. Both C64/C64C versions have been tested. Sorry for all the errors in the previous revision.

Closed 2022-01-30.

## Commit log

2021-05-28 Rev 20210528-2008 - Prototype
    [C64 RF Modulator Replacement.kicad_pcb, C64 RF Modulator Replacement.sch, C64-Composite-Modulator-Bom.xlsx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]
2021-06-01 Rev 20210531-2143 - Bug Fix
    [C64-Composite-Modulator-B_Cu.gbl, C64-Composite-Modulator-B_Mask.gbs, C64-Composite-Modulator-B_Paste.gbp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]
2022-01-30 Revision 20220130-1040
    [C64-Composite-Modulator-Bom.xlsx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]
2022-01-31 Reduce the number of JLCPCB's extended parts
    [C64-Composite-Modulator-Bom.xlsx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]
2022-03-24 Updated images and release notes
    [C64-Composite-Modulator-B_Cu.gbl, C64-Composite-Modulator-B_Mask.gbs, C64-Composite-Modulator-B_Paste.gbp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]
